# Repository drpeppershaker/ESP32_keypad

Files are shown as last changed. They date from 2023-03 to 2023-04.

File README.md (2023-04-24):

# ESP32_keypad

This DIY macropad is built with only off-the-shelf parts. No custom PCBs for absolute ease of building! It uses an ESP32 with [ESPHome](https://esphome.io/) in order to control devices or trigger automations in [Home Assistant](https://home-assistant.io). <br><br>
It has 8 keys, and supports different actions for single, double, and triple clicks, long clicks, and click and holds.

<p align="center">
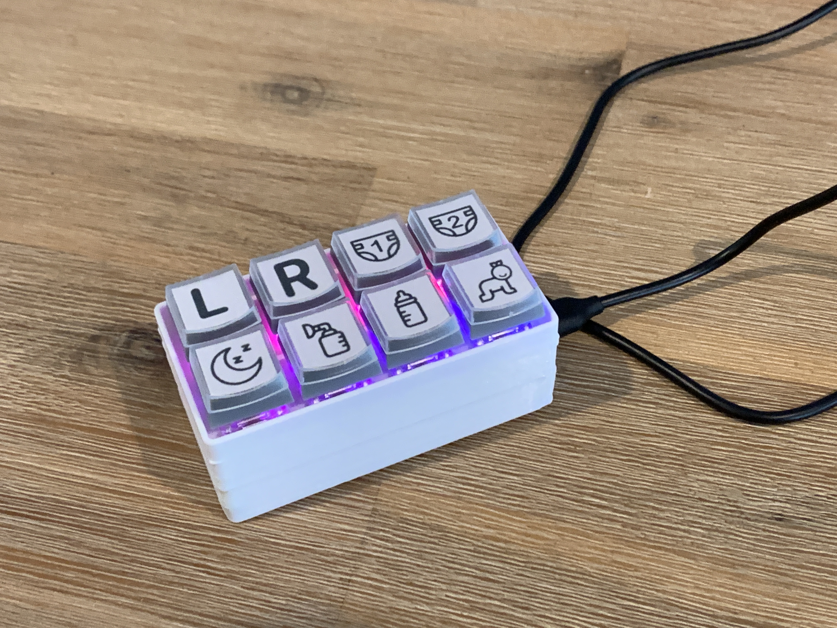
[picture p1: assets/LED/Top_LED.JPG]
  
  
  <br>LED Version<br><br>
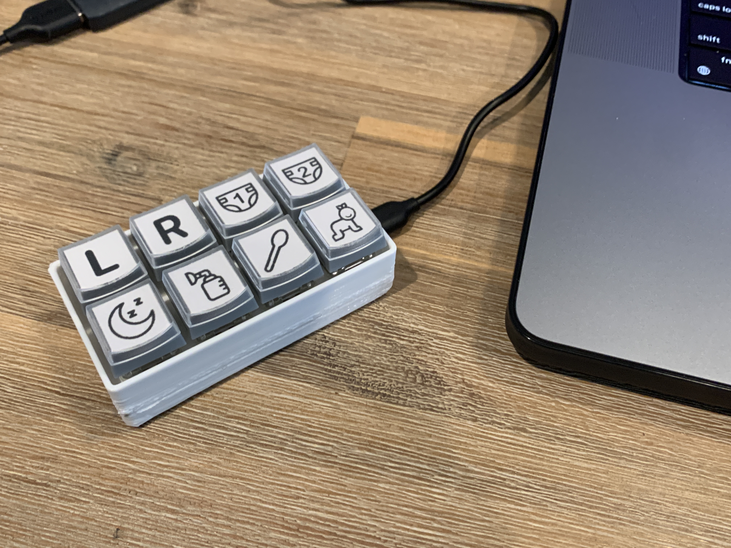
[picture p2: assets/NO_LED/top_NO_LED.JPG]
  
  <br>NO_LED version
</p>

## Versions
### NO_LED 
- As the names suggest, the NO_LED version does not use any LEDs. This keeps the cost and soldering skills required lower.
### LED
- The LED version uses 16 addressable LEDs -- 8 LEDs for RGB backlighting with various effects and 1 LED for each individual key for reactive keypresses. This version is a few millimeters taller than the NO_LED version to accommodate the LED Pixels.

## Requirements
- [Home Assistant installation](https://www.home-assistant.io)
- [ESPHome integration](https://www.home-assistant.io/integrations/esphome/)

## Building the Macro Pad

<details><summary><h2>LED VERSION</h2> (Click to expand) </summary>

### Tools
| **Tool** | **Non Referral Link** | **Referral Link** | **Notes** |
|---|---|---|---|
| Soldering Iron Kit | https://www.amazon.com/dp/B08R3515SF | https://amzn.to/3JADtWo | This is not the soldering iron kit I used. I use a [Pinecil](https://amzn.to/3K6qU6E) by Pine64, which I can't recommend enough. But if you're just doing one project--just grab a full kit with all the do-dads you need. |
| Silicone Wire | https://www.amazon.com/dp/B01LH1G2IE | https://amzn.to/40wMlTD | Silicone wire is helpful for wiring the switches to the board. It's  extra flexible, which helps with the smash and cram at the end. |
| Solid Core Wire | https://www.amazon.com/dp/B09BFFJRST | https://amzn.to/3lhCEd2 | Solid core wire is practically a requirement to wire up the LED Pixels.  In my original prototype I used the legs from a few resistors, and some header  pins instead of solid core wire. It was a PAIN to wire that way. Go with some solid core wire... |
| M3 Bolts | https://www.amazon.com/dp/B0B31SC98Z | https://amzn.to/3nlqikM | M3 Socket Cap bolts for the 3D Printed Case |
| Tiny Screws | https://www.amazon.com/dp/B09L4R6B1Q | https://amzn.to/3JLnSDx | I used some tiny screws to attach the ESP32 board to the bottom of the case. |
<p align="center"><sup>If you choose to use the above affiliate links I <i>may</i> receive a very small commision from Amazon at no extra cost to you</sup></p>

### Parts
| **Parts** | **Referral Link** | **Non-Referral Link** | **Notes** |
|---|---|---|---|
| 8 Cherry MX Switches | https://amzn.to/3YT6VgA | https://www.amazon.com/dp/B07KMXJ4KG | I like the Blue switches because  they're *very* click-y |
| an ESP32 board | https://amzn.to/41l7mCi | https://www.amazon.com/dp/B08DR31G4G | These are to the cheapest ESP32 boards I could find on Amazon. Use whatever boards you like |
| Relegendable Keycaps | https://amzn.to/3SmIaqX | https://www.amazon.com/dp/B01M023NFK | Originally I went with the grey keycaps, but switched to the translucent keycaps when I put the LEDs in. |
| Addressable LEDs (LED VERSION) | https://amzn.to/3yH5whK | https://www.amazon.com/dp/B01DC0J0WS | I used these pixels because all the LED strips I have are low density and the Pixels are too spread out. I really wanted to cram two LEDs behind each key switch, and this seems like the simplest way to achieve that. After building two keypads with LEDs, I think that someone who isn't me should attempt this with an LED strip with 144 pixel/m strips. You should be able to fit two leds behind each key with that kind of density. | 
<p align="center"><sup>If you choose to use the above affiliate links I <i>may</i> receive a very small commision from Amazon at no extra cost to you</sup></p>

### Assembly
- all switches are now connected to common GND and to their respective GPIOs (see ESPHome YAML files)
  - Note, your GPIO pins may be different based on the version of the board you use. I'm using the built-in PULLUP resistors on the ESP32 board for the switches. If you need to switch GPIO pins, make sure you use pins that have PULLUP resistors.
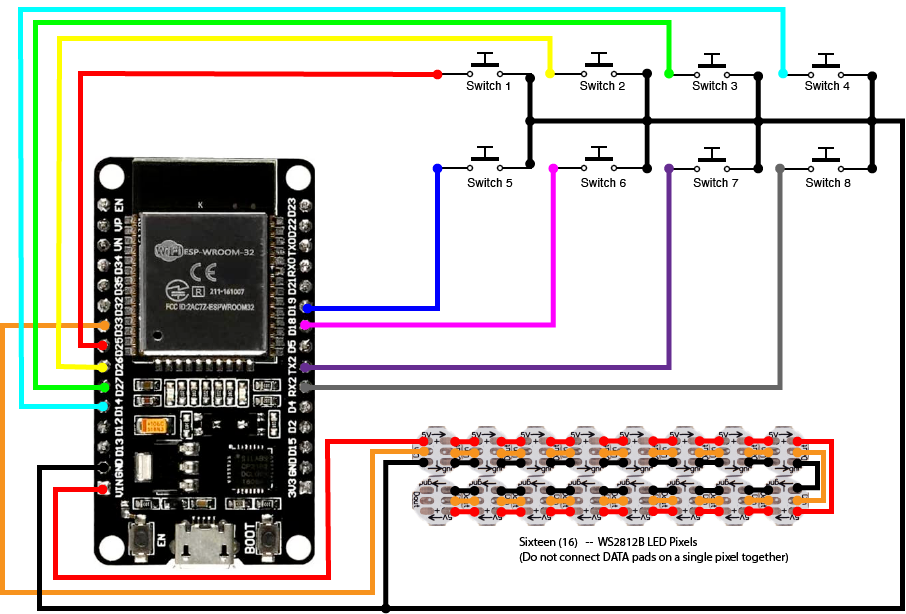
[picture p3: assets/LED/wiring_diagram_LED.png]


<br><br>
<table>
<tbody>
  <tr>
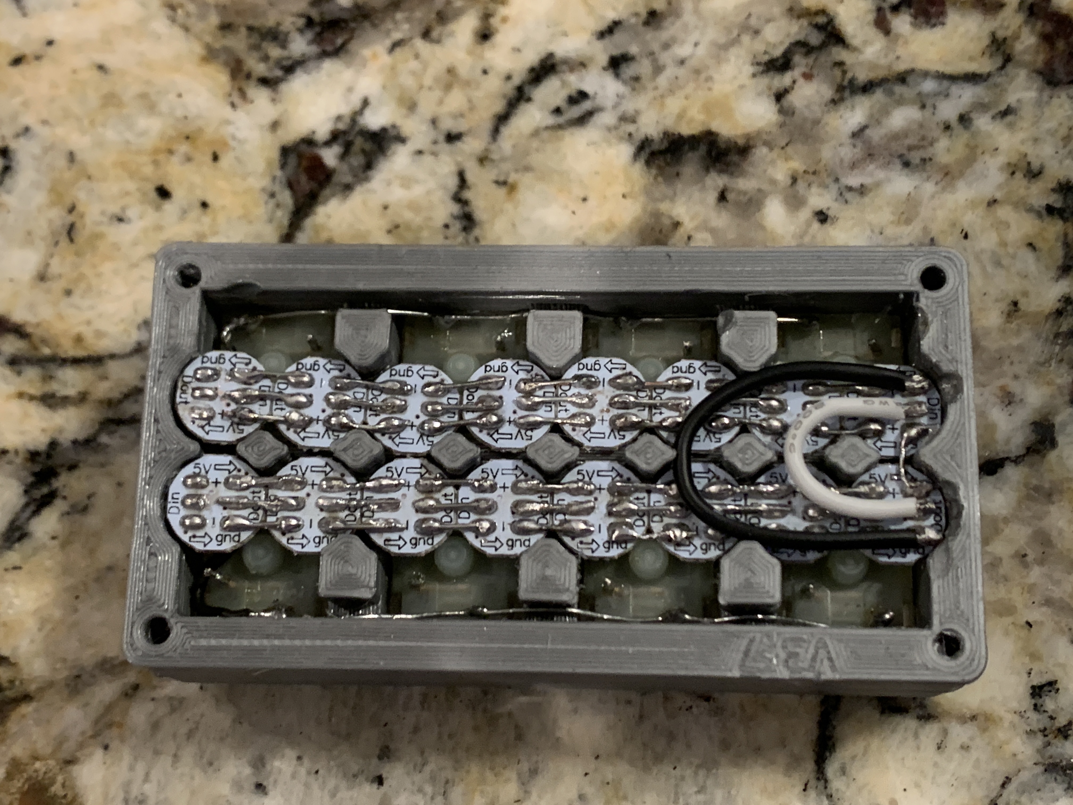
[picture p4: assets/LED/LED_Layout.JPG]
    <td></th>
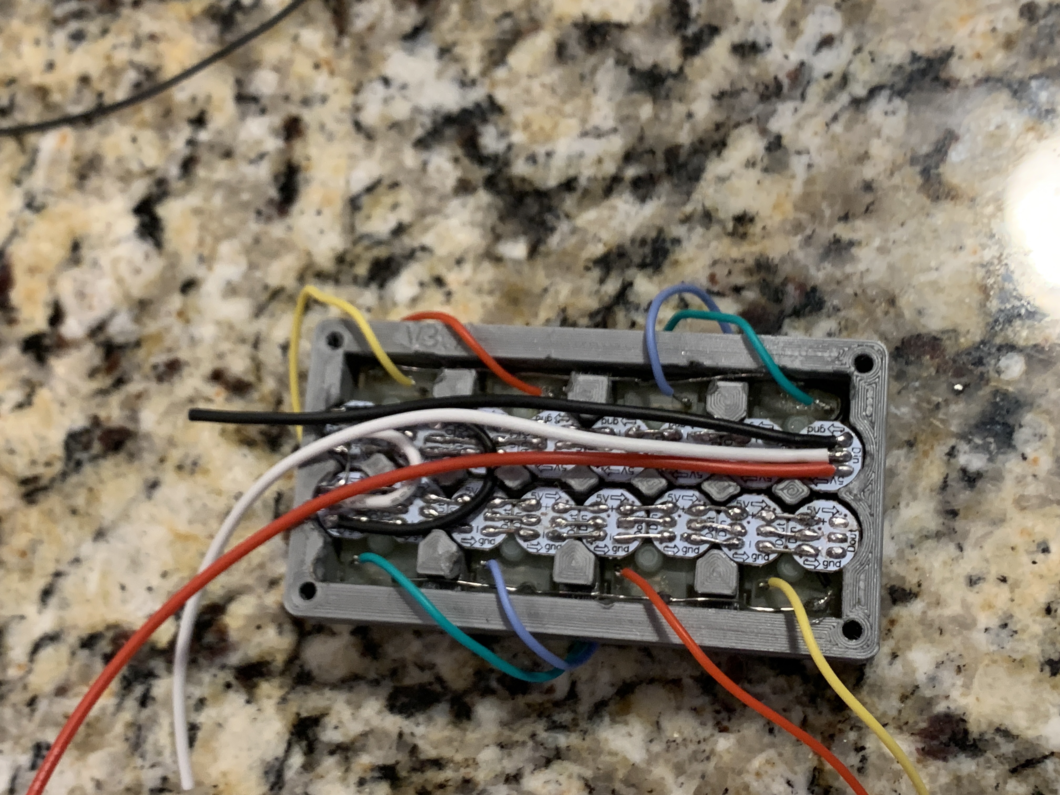
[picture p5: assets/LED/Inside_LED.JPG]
    <td></th>
  </tr>
  <tr>
    <td>Leds Wired and test fit.</td>
    <td>All switches **connected to common GND** rather than VIN.</td>
  </tr>
</tbody>
</table>

The LED pixels are sold in a 10x10 grid. The PCBs for each LED are attached to one another, but they are easy to break apart. You will want to keep them attached in two separate 'strips' of 8 connected leds each. Don't try to break them into individual pixels because they'll fall through the case.

NOTE: When wiring up the LED pixels, you *can* have a single solid wire for all the 5V and one for all the GND contacts. However, the data contacts must be separated and move from DIN to DOUT--they can't be connected on the same pixel or they will NOT work. Stick to the wiring diagram for the Data Line.

### Case
[STL files here](/3D_files)
- I 3D printed my case. I've included two versions of the macropad case bottom. The images from V1 is using the 'short_bottom'. The short bottom version of the case makes things very tight, but everything should fit if you are careful with your wiring. Run the wires along the sides of the board, and keep them trimmed short. That said, If you don't want to put your soldering skills and smash and cram skills to the test, I also included a slightly taller version as well. The V2 version of the keypad w/ the LEDs that I made was testing my patience already, so I just put it in the taller version of the case. Certainly much easier, and not *that* much taller overall.

- The V2 top case has cutouts for the LED pixels and for the common ground wire. This can be printed without supports, your printer must be at least *kinda* dialed in. You can see my pictures--my printer isn't all that calibrated, and I was still able to print this without supports. The real trick is to print it SLOWLY. The slower you print it, the better chance you'll have of not knocking off the the little center posts, plus your bridging will be better. I dialed my printer back to 35mm/s on both walls and infill and all the way down to 25mm/s for bridging. 
- You will probably want to set your slicer to print the external perimeters first. The case is designed for the key switches to be pressure fit. Printing the outer walls first will help keep the print from over expanding and making your switches not fit. You can also dial back your flow settings to help keep things fitting as they should. If you're still struggling, you can also increase the dimensions of the STLs by 1 or 2 percent to help things fit a bit easier. NOTE: I have not tested printing the case larger, so I don't know how well the LEDs will fit when you size it up.
- Finally, I'm not a 3D designer or engineer. I adapted the original design from thingiverse for my needs using Tinkercad. 
  - [Macropad Top on Tinkercad](https://www.tinkercad.com/things/466cJwJKiFd-macropadv2topver37)
  - [Macropad Bottoms on Tinkercad](https://www.tinkercad.com/things/ekNTHmUWMJU-esp32macropadbottoms)

</details>

<details><summary><h2>NO_LED VERSION</h2>  (Click to expand) </summary>
  
### Tools
| **Tool** | **Non Referral Link** | **Referral Link** | **Notes** |
|---|---|---|---|
| Soldering Iron Kit | https://www.amazon.com/dp/B08R3515SF | https://amzn.to/3JADtWo | This is not the soldering iron kit I used. I use a [Pinecil](https://amzn.to/3K6qU6E) by Pine64, which I can't recommend enough. But if you're just doing one project--just grab a full kit with all the do-dads you need. |
| Silicone Wire | https://amzn.to/40wMlTD | https://www.amazon.com/dp/B01LH1G2IE | Silicone wire is helpful for wiring the switches to the board. It's  extra flexible, which helps with the smash and cram at the end. |
| Solid Core Wire | https://amzn.to/3lhCEd2 | https://www.amazon.com/dp/B09BFFJRST | Solid core wire is practically a requirement to wire up the LED Pixels.  In my original prototype I used the legs from a few resistors, and some header  pins instead of solid core wire. It was a PAIN to wire that way. Go with some solid core wire... |
| M3 Bolts | https://www.amazon.com/dp/B0B31SC98Z | https://amzn.to/3nlqikM | M3 Socket Cap bolts for the 3D Printed Case |
| Tiny Screws | https://www.amazon.com/dp/B09L4R6B1Q | https://amzn.to/3JLnSDx | I used some tiny screws to attach the ESP32 board to the bottom of the case. |
<p align="center"><sup>If you choose to use the above affiliate links I <i>may</i> receive a very small commision from Amazon at no extra cost to you</sup></p>

### Parts
| **Parts** | **Referral Link** | **Non-Referral Link** | **Notes** |
|---|---|---|---|
| 8 Cherry MX Switches | https://amzn.to/3YT6VgA | https://www.amazon.com/dp/B07KMXJ4KG | I like the Blue switches because  they're *very* click-y |
| an ESP32 board | https://amzn.to/41l7mCi | https://www.amazon.com/dp/B08DR31G4G | These are to the cheapest ESP32 boards I could find on Amazon. Use whatever boards you like |
| Relegendable Keycaps | https://amzn.to/3SmIaqX | https://www.amazon.com/dp/B01M023NFK | |
                   
<p align="center"><sup>If you choose to use the above affiliate links I <i>may</i> receive a very small commision from Amazon at no extra cost to you</sup></p>

### Assembly
- all switches are now connected to common GND and to their respective GPIOs (see ESPHome YAML files)
  - Note, your GPIO pins may be different based on the version of the board you use. I'm using the built-in PULLUP resistors on the ESP32 board for the switches. If you need to switch GPIO pins, make sure you use pins that have PULLUP resistors.
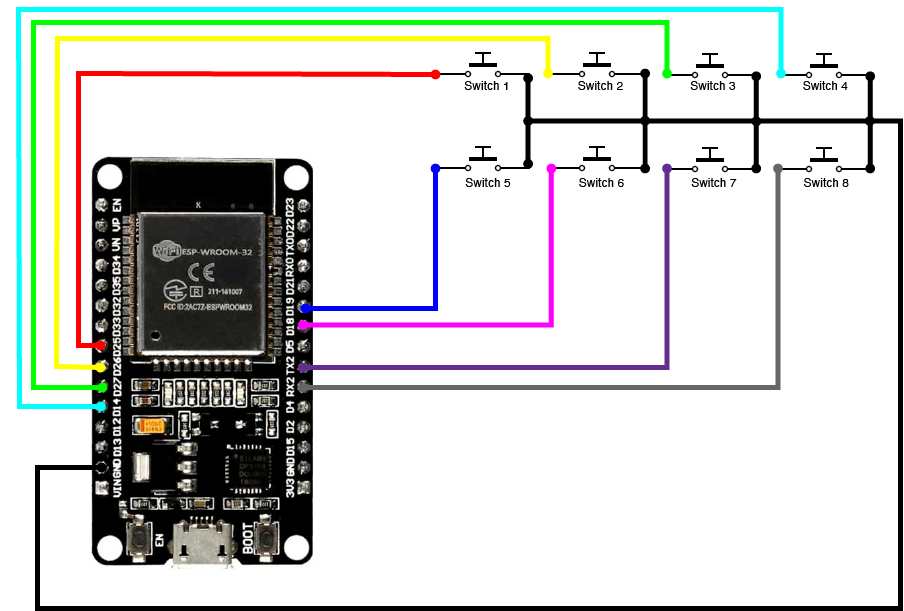
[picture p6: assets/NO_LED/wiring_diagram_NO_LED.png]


<br><br>

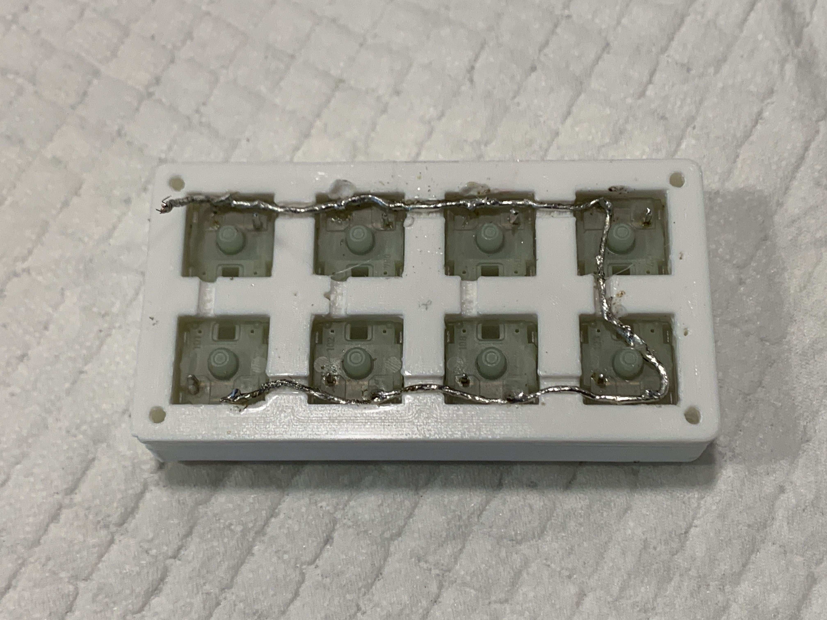
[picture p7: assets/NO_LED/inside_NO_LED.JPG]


### Case
[STL files here](/3D_files)
- I 3D printed my case. I've included two versions of the macropad case bottom. The images from the NO_LED version is using the 'short_bottom'. The short bottom version of the case makes things very tight, but everything should fit if you are careful with your wiring. Run the wires along the sides of the board, and keep them trimmed short. That said, If you don't want to put your soldering skills and smash and cram skills to the test, I also included a slightly taller version as well.

- You can use the LED version of the case and it will still work well for the non-led version of the keypad. However, the LED version of the case requires your printer to be more dialed in, and you will likely need to print slower because it has more overhangs.
- You will probably want to set your slicer to print the external perimeters first. The case is designed for the key switches to be pressure fit. Printing the outer walls first will help keep the print from over expanding and making your switches not fit. You can also dial back your flow settings to help keep things fitting as they should. If you're still struggling, you can also increase the dimensions of the STLs by 1 or 2 percent to help things fit a bit easier. NOTE: I have not tested printing the case larger, so I don't know how well the LEDs will fit when you size it up.
- Finally, I'm not a 3D designer or engineer. I adapted the original design from thingiverse for my needs using Tinkercad. 
  - [Macropad Top on Tinkercad](https://www.tinkercad.com/things/466cJwJKiFd-macropadv2topver37)
  - [Macropad Bottoms on Tinkercad](https://www.tinkercad.com/things/ekNTHmUWMJU-esp32macropadbottoms)

</details>

## Programming
- Add your ESP device to Home Assistant once detected
- Install esp32_keypad.yaml
- Add your own automations (you can use the one here for inspiration). 
  - Note: this uses events rather than binary sensors for recording multi-clicks.

## Icons
[icons here](/icons)
- I've included individual icons, a printable template, and a blank template for printing out your own icons for your relegendable keycaps.

## Credits
inspired by: 
- https://github.com/sfgabe/OITProjects/tree/master/Baby_Buddy_Keypad 
- https://github.com/jeroenterheerdt/Baby-Buddy-Keypad. 

STLs:
- Remixed from ['Macro Pad' on Thingiverse](https://www.thingiverse.com/thing:5628107) by tomtompoperdom

icons:
- [Icons for keypad courtesy of Freepik on Flaticon](https://www.flaticon.com/authors/freepik)
- [blank template courtesy of X-keys](https://xkeys.com/)

Special Thanks:
- [jesserockz](https://github.com/jesserockz) & [ssieb](https://github.com/ssieb) on the [ESPHome Discord](https://discord.com/invite/KhAMKrd) for all the support getting this thing working.

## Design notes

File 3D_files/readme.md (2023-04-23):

## 3D Files

- ESP32\_keypad\_short_bottom.stl - Mount the esp32 'upside-down' and screw in with the tiniest screws you can find.
- ESP32\_keypad\_tall\_bottom.stl - Taller version which should allow a _bit_ more rooom for wires/soldering
- ESP32\_Macropad\_top.stl - Top where you mount the key switches. There are groves on the bottom to help with wiring the common GND wire.

NOTE: You can absolutely use the LED version without LEDs inside of it.

## Attributions

Remixed from ['Macro Pad' on Thingiverse](https://www.thingiverse.com/thing:5628107) by tomtompoperdom

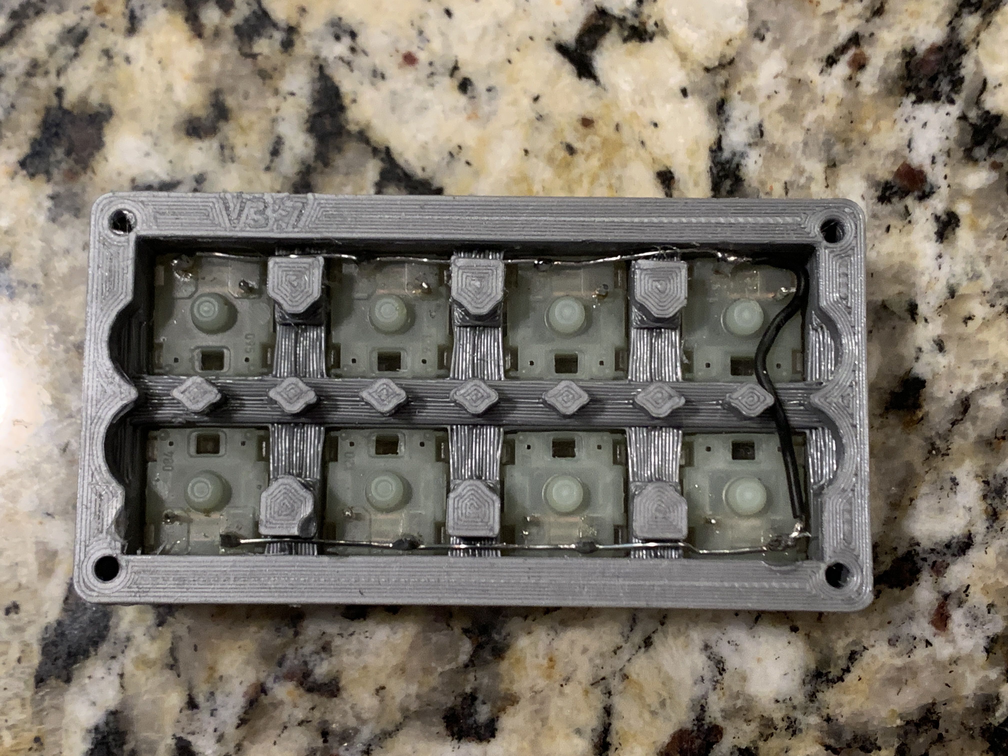
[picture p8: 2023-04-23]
assets/LED/common_GND.JPG

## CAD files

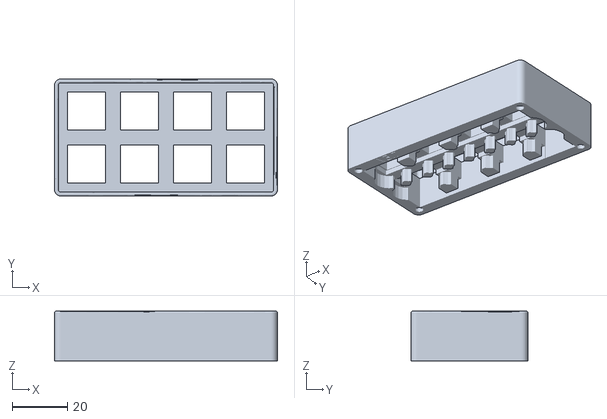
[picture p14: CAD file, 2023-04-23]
3D_files/LED/ESP32_Macropad_top_V2.stl
80.8 x 42.4 x 18.0

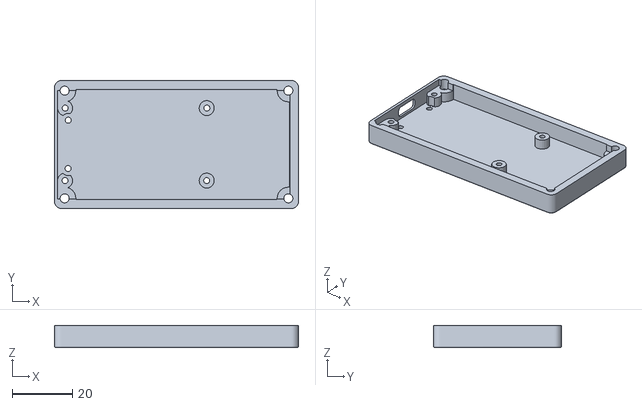
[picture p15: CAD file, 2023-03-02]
3D_files/NO_LED/ESP32_keypad_short_bottom.stl
80.8 x 42.4 x 7.37

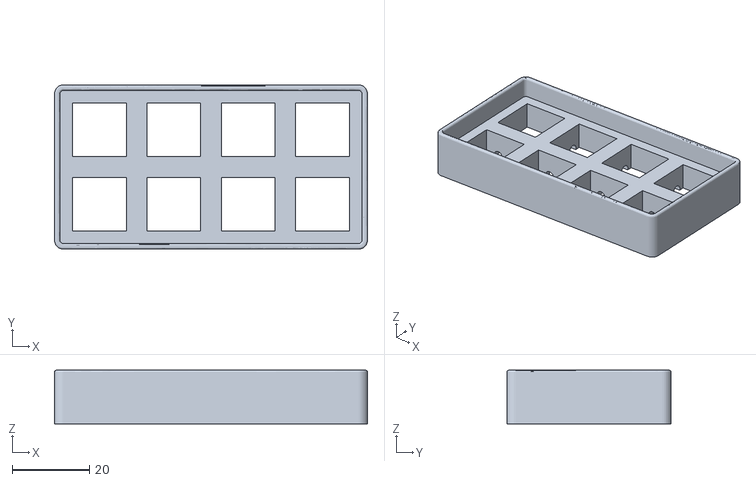
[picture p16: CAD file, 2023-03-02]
3D_files/NO_LED/ESP32_Macropad_top_V1.stl
80.8 x 42.4 x 13.8

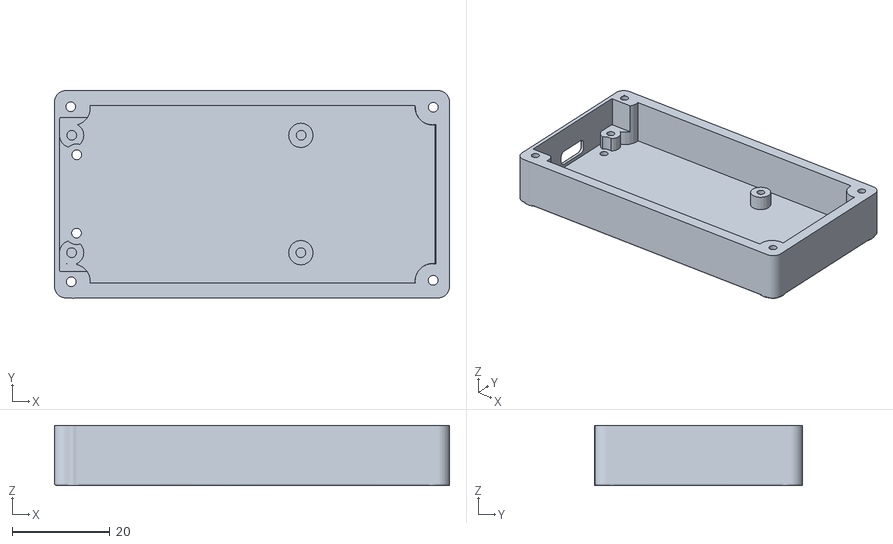
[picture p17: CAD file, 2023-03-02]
3D_files/LED/ESP32_keypad_tall_bottom.stl
80.8 x 42.5 x 12.4

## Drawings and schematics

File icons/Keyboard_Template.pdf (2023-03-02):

LR
LR

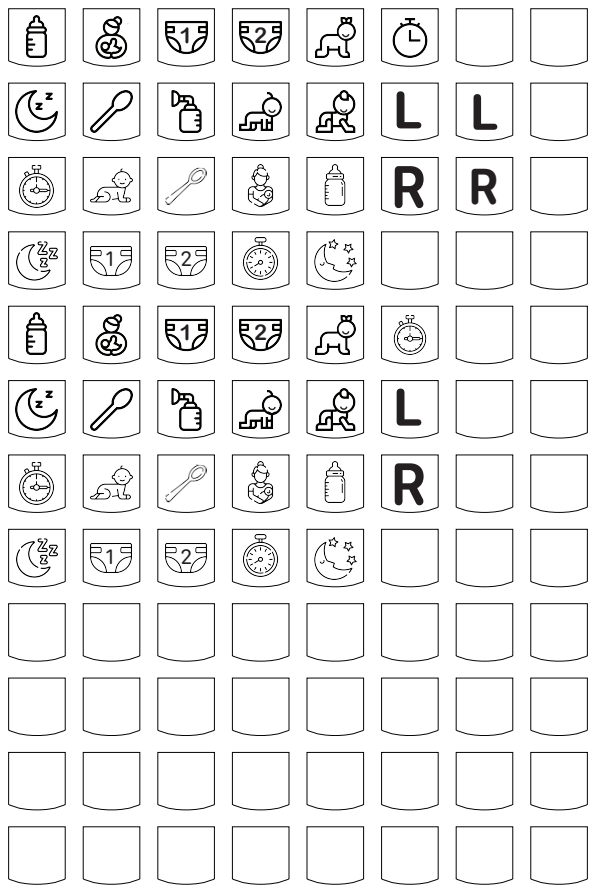
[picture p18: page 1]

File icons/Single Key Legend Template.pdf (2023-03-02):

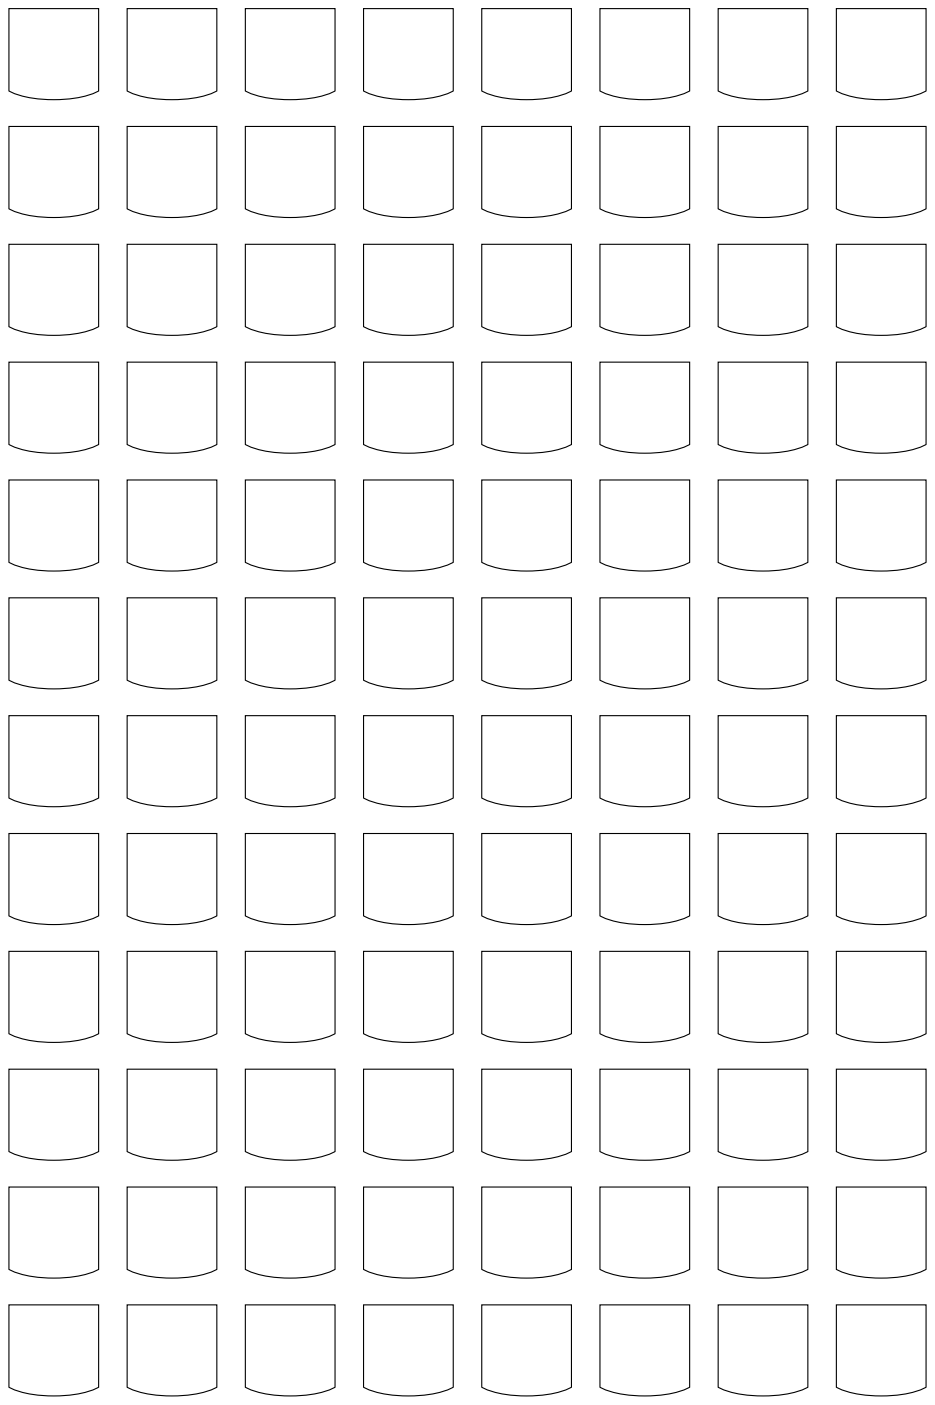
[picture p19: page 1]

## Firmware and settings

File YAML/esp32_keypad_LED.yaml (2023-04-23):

esphome:
  name: esp32-keypad
  friendly_name: eps32_keypad

esp32:
  board: esp32dev
  framework:
    type: arduino

# Enable logging
logger:

# Enable Home Assistant API
api:
  encryption:
    key: !secret api_key

ota:
  password: !secret ota_password

wifi:
  ssid: !secret wifi_ssid
  password: !secret wifi_password

  # Enable fallback hotspot (captive portal) in case wifi connection fails
  ap:
    ssid: "esp32 Keypad Fallback Hotspot"
    password: !secret ssid_password

captive_portal:

#connections: all buttons are on GND and on their respective pins
#(we are relying on esp32s built-in pullup resistors but could have used external resistors as well)
#Button 1: GPIO25 / 
#Button 2: GPIO26 / 
#Button 3: GPIO27 / 
#Button 4: GPIO14 / 

#Button 5: GPIO19 / 
#Button 6: GPIO18 / 
#Button 7: GPI17 / 
#Button 8: GPIO16 



# Light Compenent
light:
  - platform: fastled_clockless
    id: light1
    name: light1
    chipset: WS2812B
    pin: GPIO33
    num_leds: 16
    rgb_order: GRB
    default_transition_length: 0s
    restore_mode: RESTORE_AND_ON
    internal: True

# Backlights
  - platform: partition
    name: "Backlight"
    id: backlight
    default_transition_length: 0s
    restore_mode: RESTORE_AND_ON
    on_turn_on:
      then:
        - light.control:
            id: backlight
            effect: Rainbow
            brightness: 60%
    segments:
      - id: light1
        from: 0
        to: 0
      - id: light1
        from: 2
        to: 2
      - id: light1
        from: 4
        to: 4
      - id: light1
        from: 6
        to: 6
      - id: light1
        from: 8
        to: 8
      - id: light1
        from: 10
        to: 10
      - id: light1
        from: 12
        to: 12
      - id: light1
        from: 14
        to: 14
    effects:
      - pulse:
      - pulse:
          name: "Fast Pulse"
          transition_length: 0.5s
          update_interval: 0.5s
      - pulse:
          name: "Slow Pulse"
          # transition_length: 1s      # defaults to 1s
          update_interval: 2s
      - pulse:
          name: "Blink"
          transition_length: .25s      # defaults to 1s
          update_interval: .25s
      - addressable_rainbow:
          name: "Rainbow"
      - addressable_rainbow:
          name: "Rainbow Skinny"
          speed: 10
          width: 25
      - addressable_scan:
      - addressable_scan:
          name: "Scan Fast"
          move_interval: 50ms
          scan_width: 1
      - addressable_twinkle:
      - addressable_random_twinkle:
      - addressable_fireworks:
          use_random_color: true
          name: Fireworks
      - addressable_flicker:

# Light for each individual key
  - platform: partition
    name: "Key 1"
    id: key1
    segments:
      - id: light1
        from: 1
        to: 1
    default_transition_length: 0s

  - platform: partition
    name: "Key 2"
    id: key2
    segments:
      - id: light1
        from: 3
        to: 3
    default_transition_length: 0s

  - platform: partition
    name: "Key 3"
    id: key3
    segments:
      - id: light1
        from: 5
        to: 5
    default_transition_length: 0s

  - platform: partition
    name: "Key 4"
    id: key4
    segments:
      - id: light1
        from: 7
        to: 7
    default_transition_length: 0s
      
  - platform: partition
    name: "Key 5"
    id: key5
    segments:
      - id: light1
        from: 9
        to: 9
    default_transition_length: 0s

  - platform: partition
    name: "Key 6"
    id: key6
    segments:
      - id: light1
        from: 11
        to: 11
    default_transition_length: 0s

  - platform: partition
    name: "Key 7"
    id: key7
    segments:
      - id: light1
        from: 13
        to: 13
    default_transition_length: 0s

  - platform: partition
    name: "Key 8"
    id: key8
    segments:
      - id: light1
        from: 15
        to: 15
    default_transition_length: 0s
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

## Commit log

2023-03-02 commit message
    [ESP32_Macropad_top.stl, ESP32_keypad_short_bottom.stl, ESP32_keypad_tall_bottom.stl]
2023-03-06 Update esp32_keypad.yaml
    RGB lighting included
2023-03-11 Update esp32_keypad.yaml
    Changed to PULLUP resistors (inverted)
    Added Backlights and Keypad Light
    Removed irrelevant sensors
2023-03-15 3D Files Update
    Split files to V1 and V2
    [ESP32_Macropad_top_V1.stl, ESP32_Macropad_top_V2.stl, ESP32_keypad_short_bottom.stl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]
2023-03-26 Update naming from V1/V2 to NO_LED/LED
    [ESP32_Macropad_top_V1.stl, ESP32_Macropad_top_V2.stl, ESP32_keypad_short_bottom.stl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]
